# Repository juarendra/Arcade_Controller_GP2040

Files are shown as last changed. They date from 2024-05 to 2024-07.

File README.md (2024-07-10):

# Arcade_Controller_GP2040
Hardware and Firmware of Arcade Controller Based RP2040 as Microcontroller and GP2040 as Frimware

# Spesification
- Input Power VIA USB 5VDC
- GP2040 Controller Firmware
- Plugable Terminal Block and molex JST-XH for Port To External Item
- Pin Header 2x10 2.54 for Port To External Item
- LED RGB on BOARD
- Support RP2040 Raspberry Pi PICO or Weact RP2040
- I2C Port 
- LED Player Port with Resistor On board 330OHM
- 3v3 and GND port Molex for external perpose

# Privew Hardware 
<p align="center">
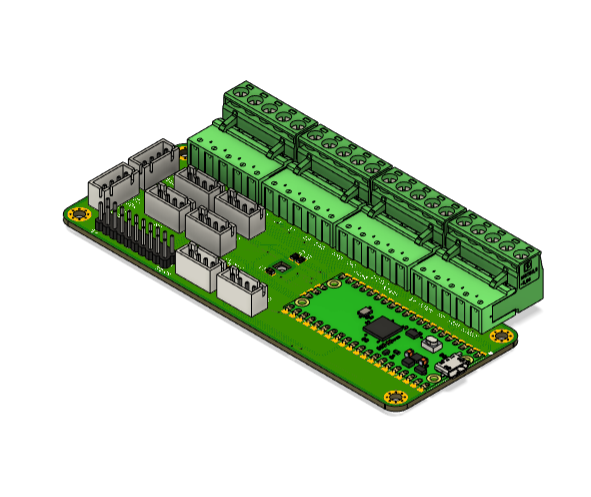
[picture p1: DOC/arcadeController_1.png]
  
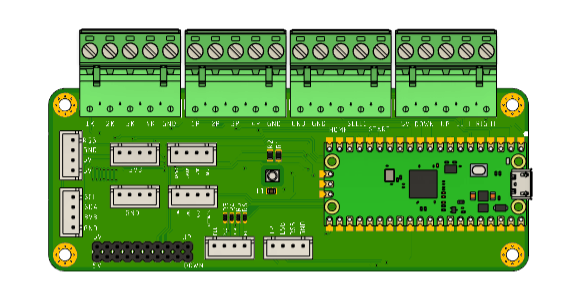
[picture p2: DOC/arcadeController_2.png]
  
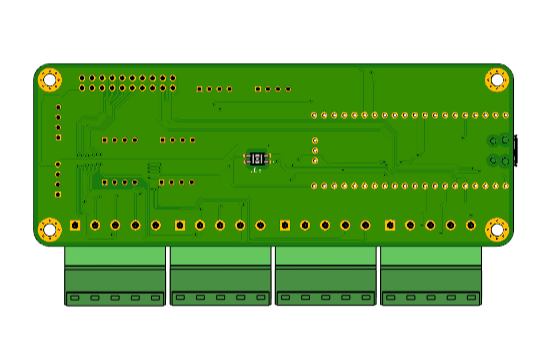
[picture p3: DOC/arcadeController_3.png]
  
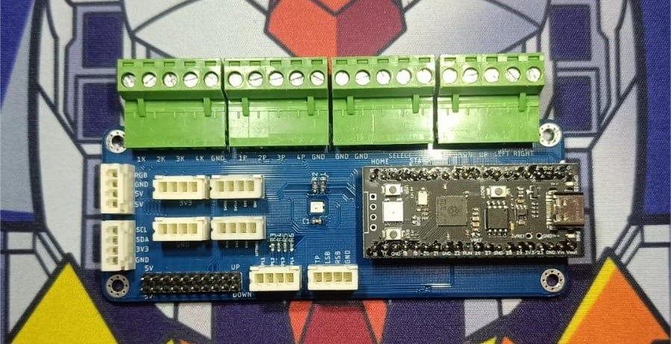
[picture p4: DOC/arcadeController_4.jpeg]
  
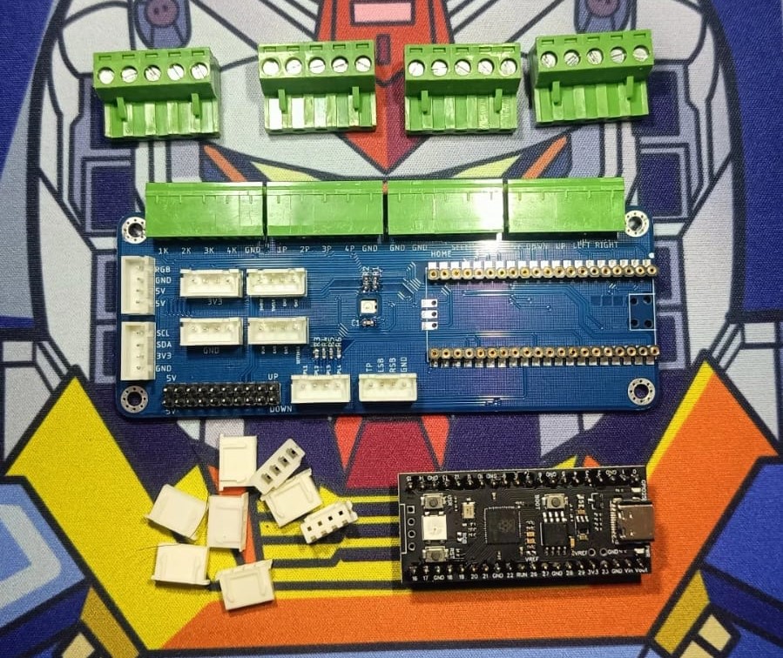
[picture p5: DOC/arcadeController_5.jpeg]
  
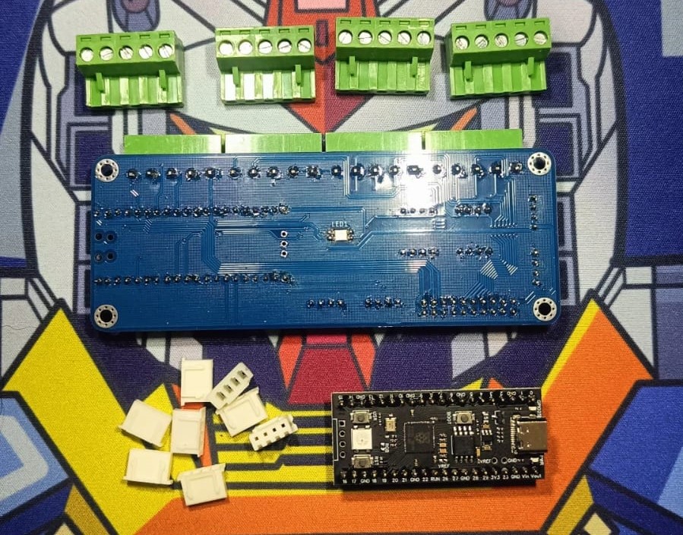
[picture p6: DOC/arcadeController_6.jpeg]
  
</p>

# Pinout
## Pinout RP2040
<p align="center">
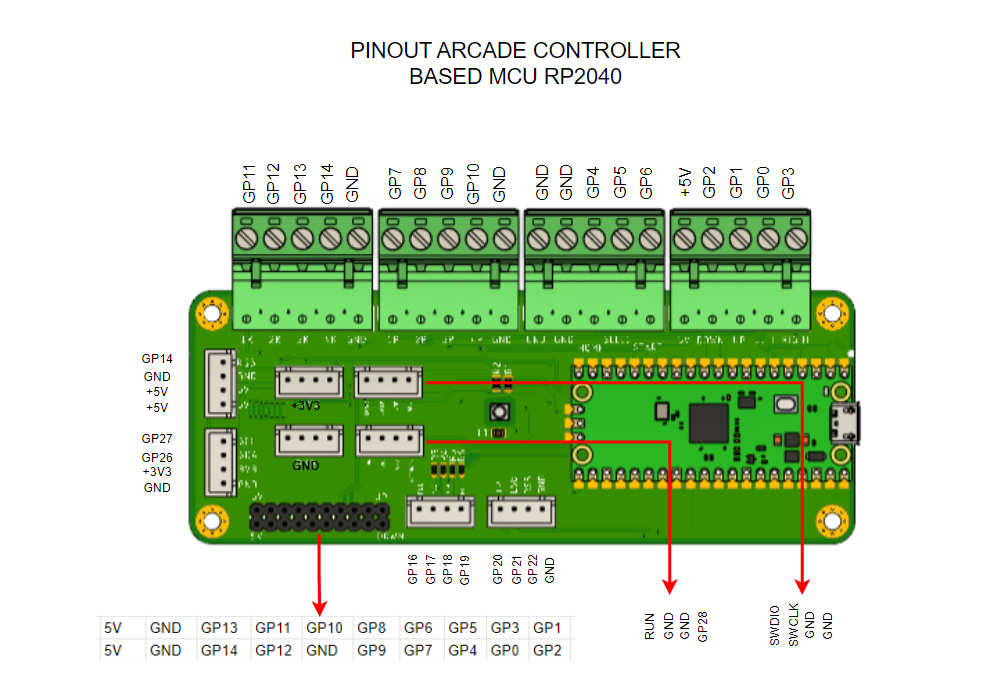
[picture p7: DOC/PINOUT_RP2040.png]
  
</p>

# Documentation 
- [Dimension](https://github.com/juarendra/Arcade_Controller_GP2040/blob/main/3D/Dimension_arcadeController.pdf)
- [BOM](https://github.com/juarendra/Arcade_Controller_GP2040/blob/main/DOC/bom.csv)
- [Pinout RP2040](https://github.com/juarendra/Arcade_Controller_GP2040/blob/main/DOC/Arcade_Controller_GP2040_Pinout.pdf)

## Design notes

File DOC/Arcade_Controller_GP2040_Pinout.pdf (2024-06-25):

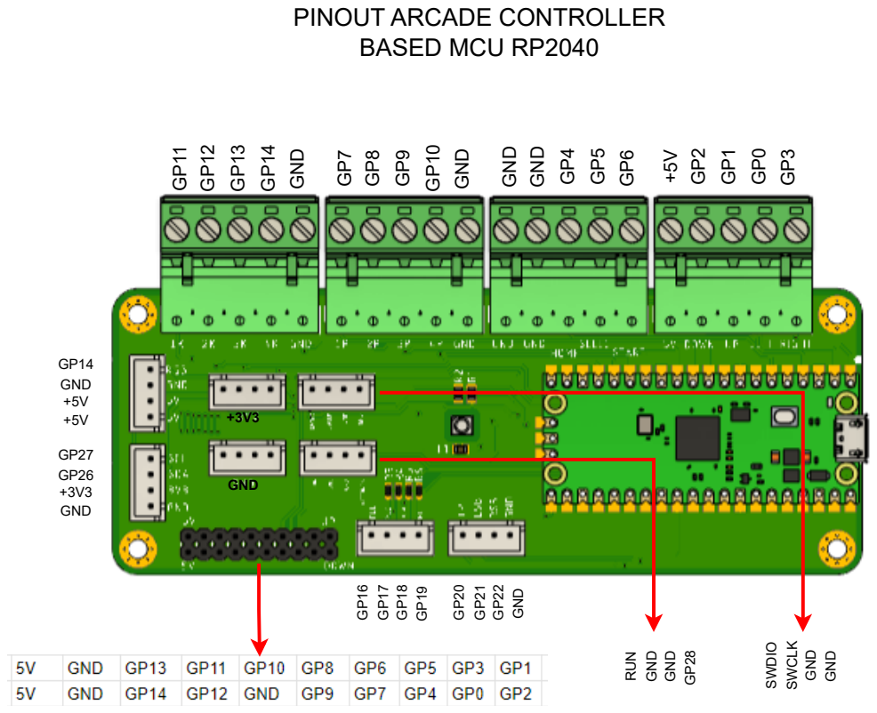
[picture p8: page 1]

PINOUT ARCADE CONTROLLER
BASED MCU RP2040

GP11

GP12

GP13

GP14
GND
GP7

GP8

GP9

GP10
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
GP14
GND
+5V
+5V

GP27
GP26
+3V3
GND

GND

+3V3

GP16

GP17

GP18
GP19

GP20
GP21

GP22
GND

SWDIO

SWCLK
RUN

GND
GND

GP28
GND
GND

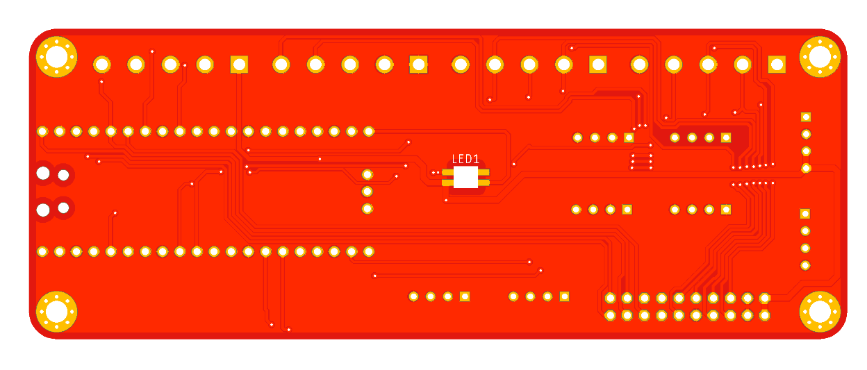
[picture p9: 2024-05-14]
DOC/rear_pcb.png

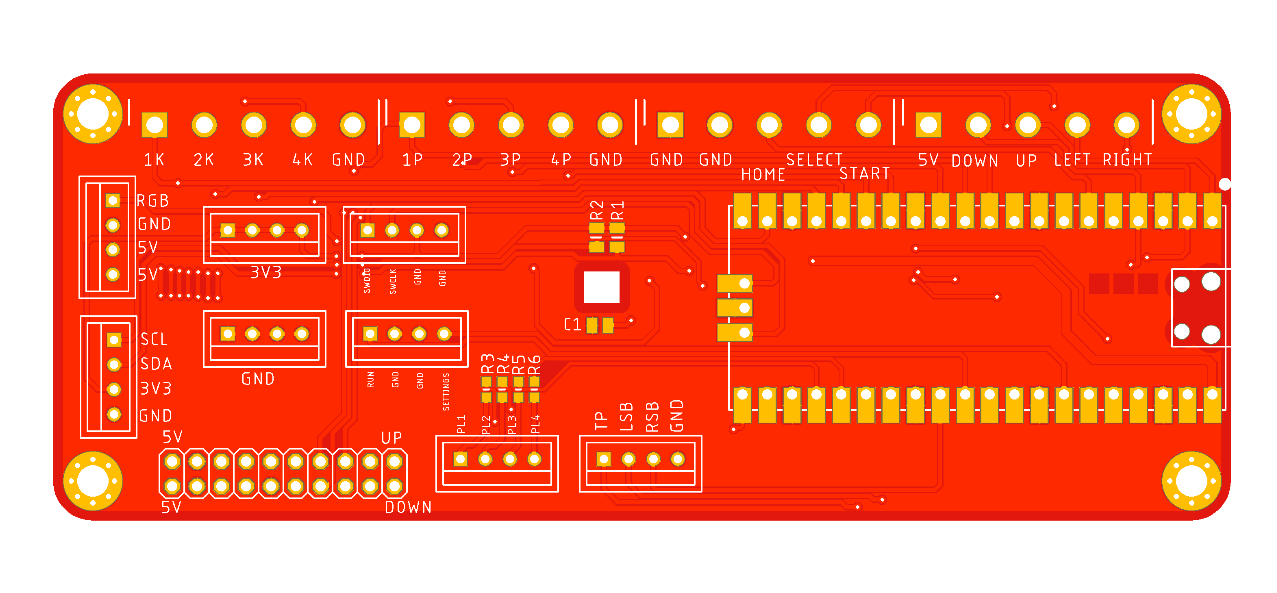
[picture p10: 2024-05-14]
DOC/front_pcb.png

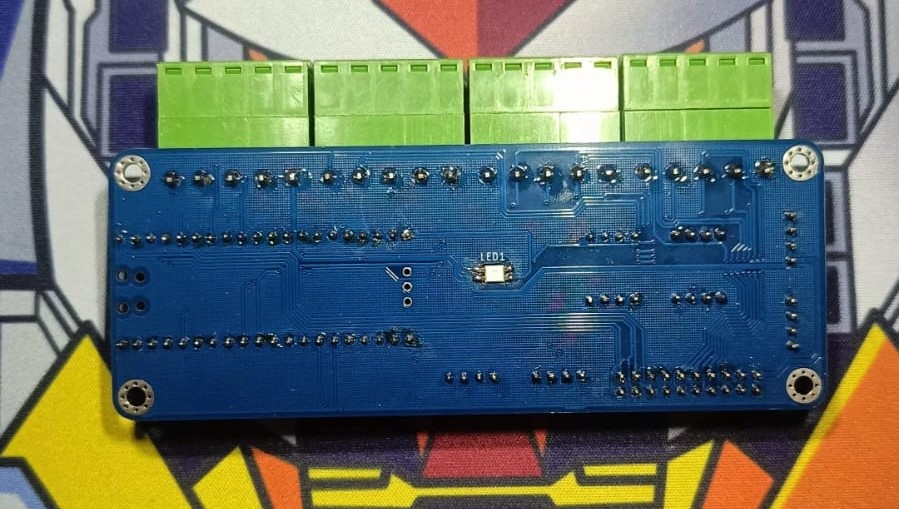
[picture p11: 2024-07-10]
DOC/arcadeController_7.jpeg

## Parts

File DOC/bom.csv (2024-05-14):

Qty | Value | Device | Package | Parts | Description | ARROW_PART_NUMBER | ARROW_PRICE-STOCK | DESCRIPTION | HEIGHT | MANUFACTURER_NAME | MANUFACTURER_PART_NUMBER | MOUSER_PART_NUMBER | MOUSER_PRICE-STOCK | POPULARITY
1 |  | PINHD-2X10 | 2X10 | JP1 | PIN HEADER |  |  |  |  |  |  |  |  | 7
8 | 04-JST-B4B-XH-A | 04-JST-B4B-XH-A | B4B-XH | X1, X2, X3, X4, X5, X6, X7, X8 | JST CONNECTOR
1 | 100nf | 08055C104K4T2A | CAPC2012X94N | C1 | AVX - 08055C104K4T2A - SMD Multilayer Ceramic Capacitor, 0.1 F, 50 V, 0805 [2012 Metric], +/- 10%, X7R |  |  | AVX - 08055C104K4T2A - SMD Multilayer Ceramic Capacitor, 0.1 F, 50 V, 0805 [2012 Metric], +/- 10%, X7R | 0.94mm | Kyocera AVX | 08055C104K4T2A | 581-08055C104K4 | https://www.mouser.co.uk/ProductDetail/KYOCERA-AVX/08055C104K4T2A?qs=xMTsDkQFXIwOG0s%252Bx1urSg%3D%3D
2 | 10k | CHP0805-FX-1002ELF | RESC2012X60N | R1, R2 | Thick Film Resistors - SMD ResHighPower 0805 10k 1% 1/2W TC100 |  |  | Thick Film Resistors - SMD ResHighPower 0805 10k 1% 1/2W TC100 | 0.6mm | Bourns | CHP0805-FX-1002ELF | 652-CHP0805FX1002ELF | https://www.mouser.co.uk/ProductDetail/Bourns/CHP0805-FX-1002ELF?qs=lc2O%252BfHJPVaDI6gsPdDtfw%3D%3D
4 | 1759046 | 1759046 | SHDRRA5W103P0X508_1X5_2540X120 | J2, J3, J4, J5 | PCB header, nominal cross section: 2.5 mm?, color: green, nominal current: 12 A, rated voltage (III/2): 320 V, contact surface: Tin, type of contact: Male connector, Number of potentials: 5, Number of rows: 1, Number of positions per row: 5, number of connections: 5, product range: MSTB 2,5/..-G, pitch: 5.08 mm, mounting: Wave soldering, pin layout: Linear pinning, solder pin [P]: 3.2 mm, Stecksystem: CLASSIC COMBICON, Locking: without, type of packaging: packed in cardboard |  |  | PCB header, nominal cross section: 2.5 mm?, color: green, nominal current: 12 A, rated voltage (III/2): 320 V, contact surface: Tin, type of contact: Male connector, Number of potentials: 5, Number of rows: 1, Number of positions per row: 5, number of connections: 5, product range: MSTB 2,5/..-G, pitch: 5.08 mm, mounting: Wave soldering, pin layout: Linear pinning, solder pin [P]: 3.2 mm, Stecksystem: CLASSIC COMBICON, Locking: without, type of packaging: packed in cardboard | 8.72mm | Phoenix Contact | 1759046 | 651-1759046 | https://www.mouser.co.uk/ProductDetail/Phoenix-Contact/1759046?qs=cyzODkzcbwC75vUJEckceg%3D%3D
4 | 330 | CMP0603AFX-3300ELF | RESC1608X55N | R3, R4, R5, R6 | Thick Film Resistors - SMD 330 OHM 1% 1/4W TC100 |  |  | Thick Film Resistors - SMD 330 OHM 1% 1/4W TC100 | 0.55mm | Bourns | CMP0603AFX-3300ELF | 652-CMP0603AFX-3300L | https://www.mouser.co.uk/ProductDetail/Bourns/CMP0603AFX-3300ELF?qs=TiOZkKH1s2QD9kDdDwF%252BdA%3D%3D
4 | 3MM_HOLE | 3MM_HOLE | 3MM_HOLE | H1, H2, H3, H4 | Cool looking 3mm hole with ground connection
1 | RASPBERRY_PICOSMD-TH | RASPBERRY_PICOSMD-TH | PICO-PKG | U1 | Raspberry Pi Pico
1 | SK6812MINI-E | SK6812MINI-E | SK6812MINIE | LED1 | 3.2x2.8x1.78 mm 0.2W Intelligent external control surface mount SMD LED (MSL:5a) |  |  | 3.2x2.8x1.78 mm 0.2W Intelligent external control surface mount SMD LED (MSL:5a) | 1.88mm | Yellow Stone Corp. | SK6812MINI-E

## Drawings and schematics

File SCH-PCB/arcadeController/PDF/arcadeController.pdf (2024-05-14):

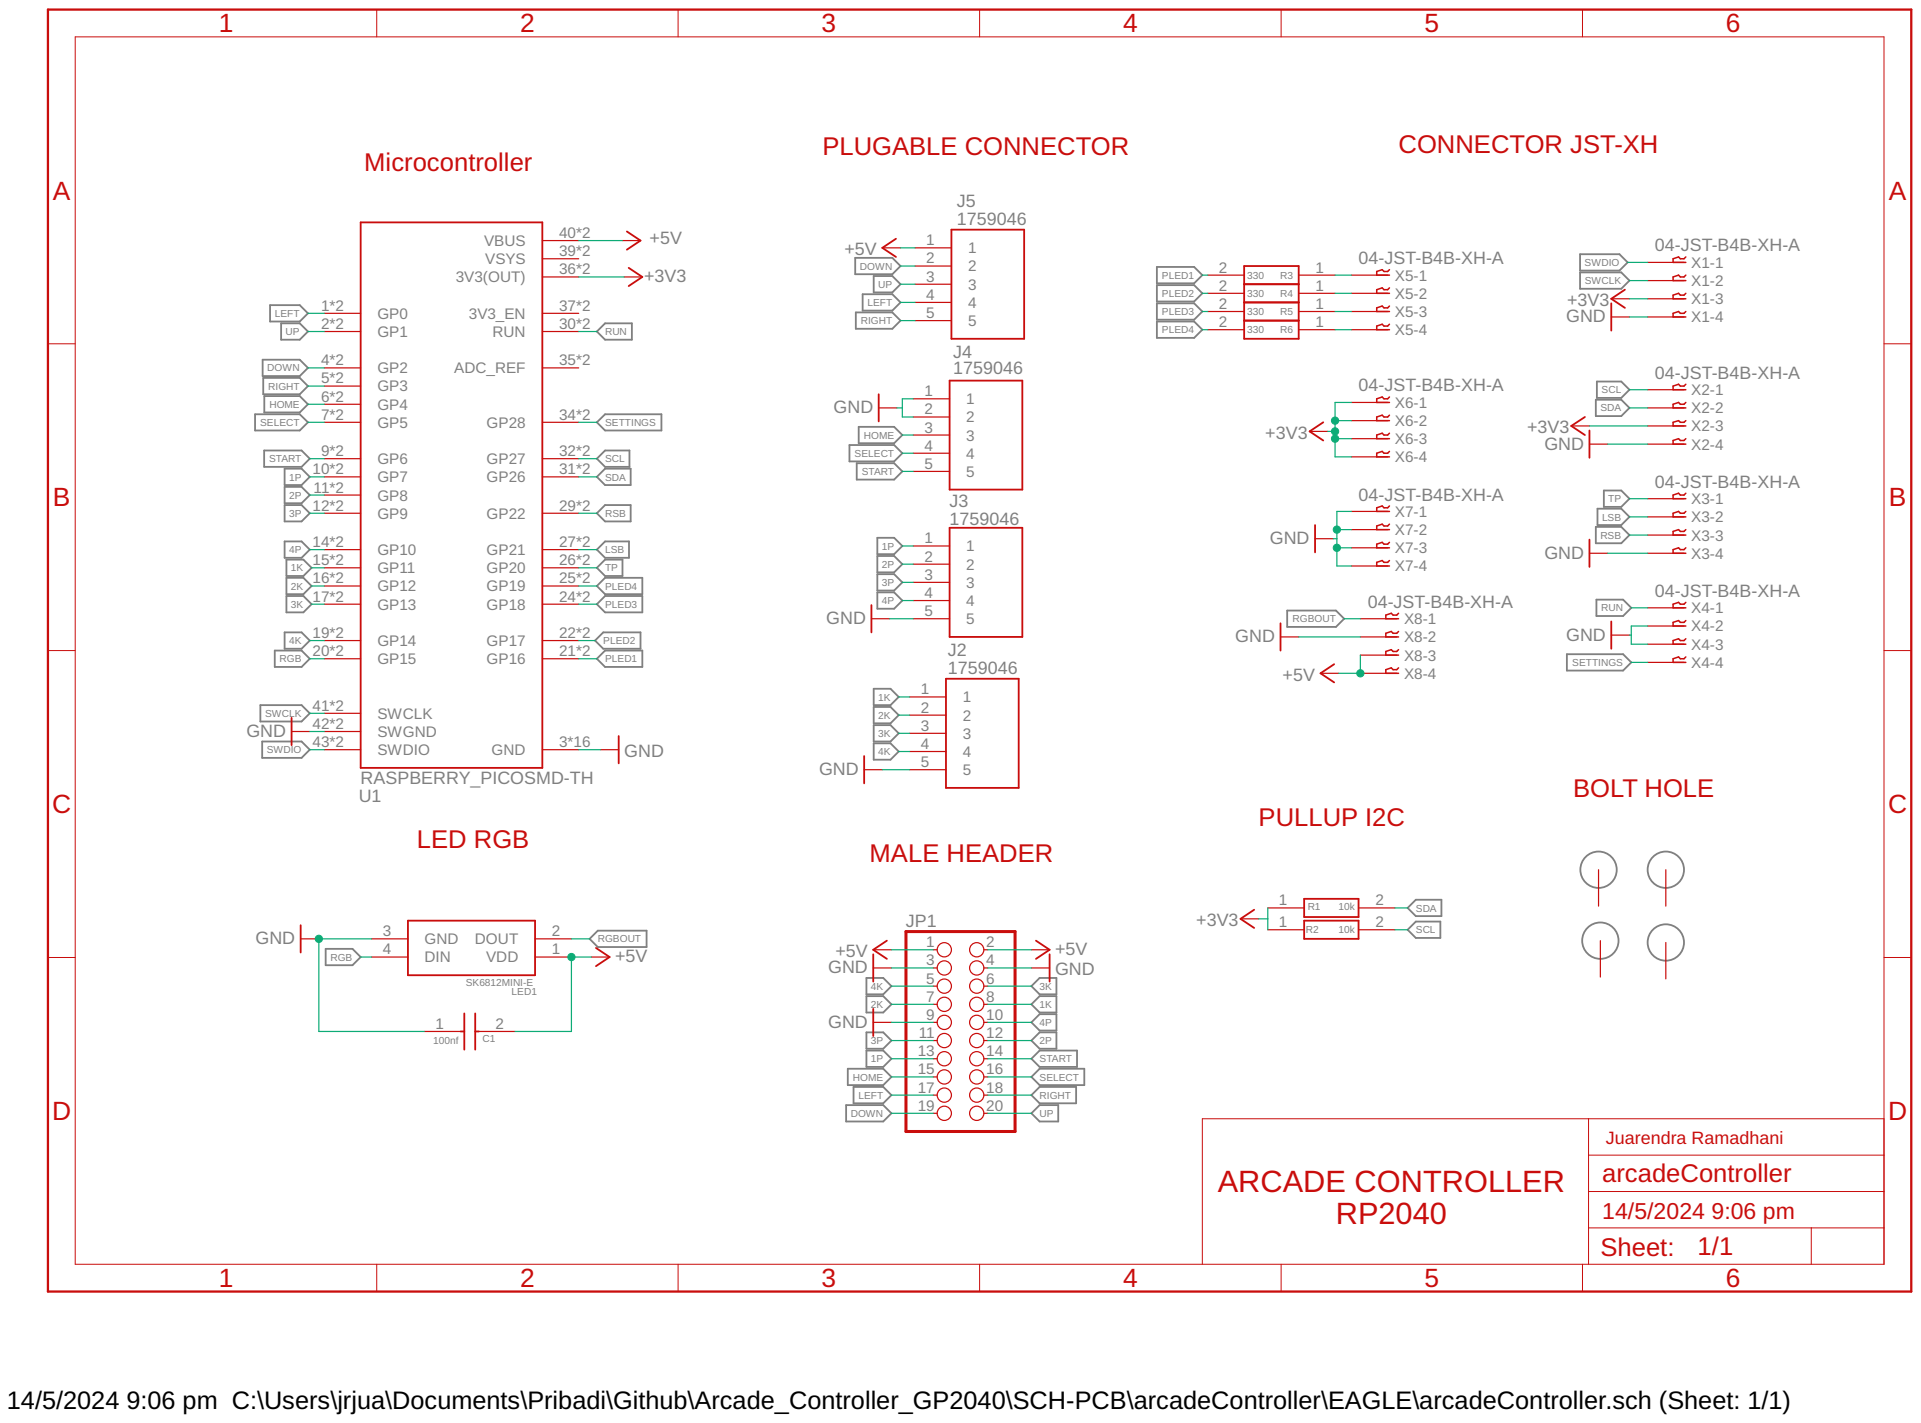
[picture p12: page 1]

14/5/2024 9:06 pm C:\Users\jrjua\Documents\Pribadi\Github\Arcade_Controller_GP2040\SCH-PCB\arcadeController\EAGLE\arcadeController.sch (Sheet: 1/1)

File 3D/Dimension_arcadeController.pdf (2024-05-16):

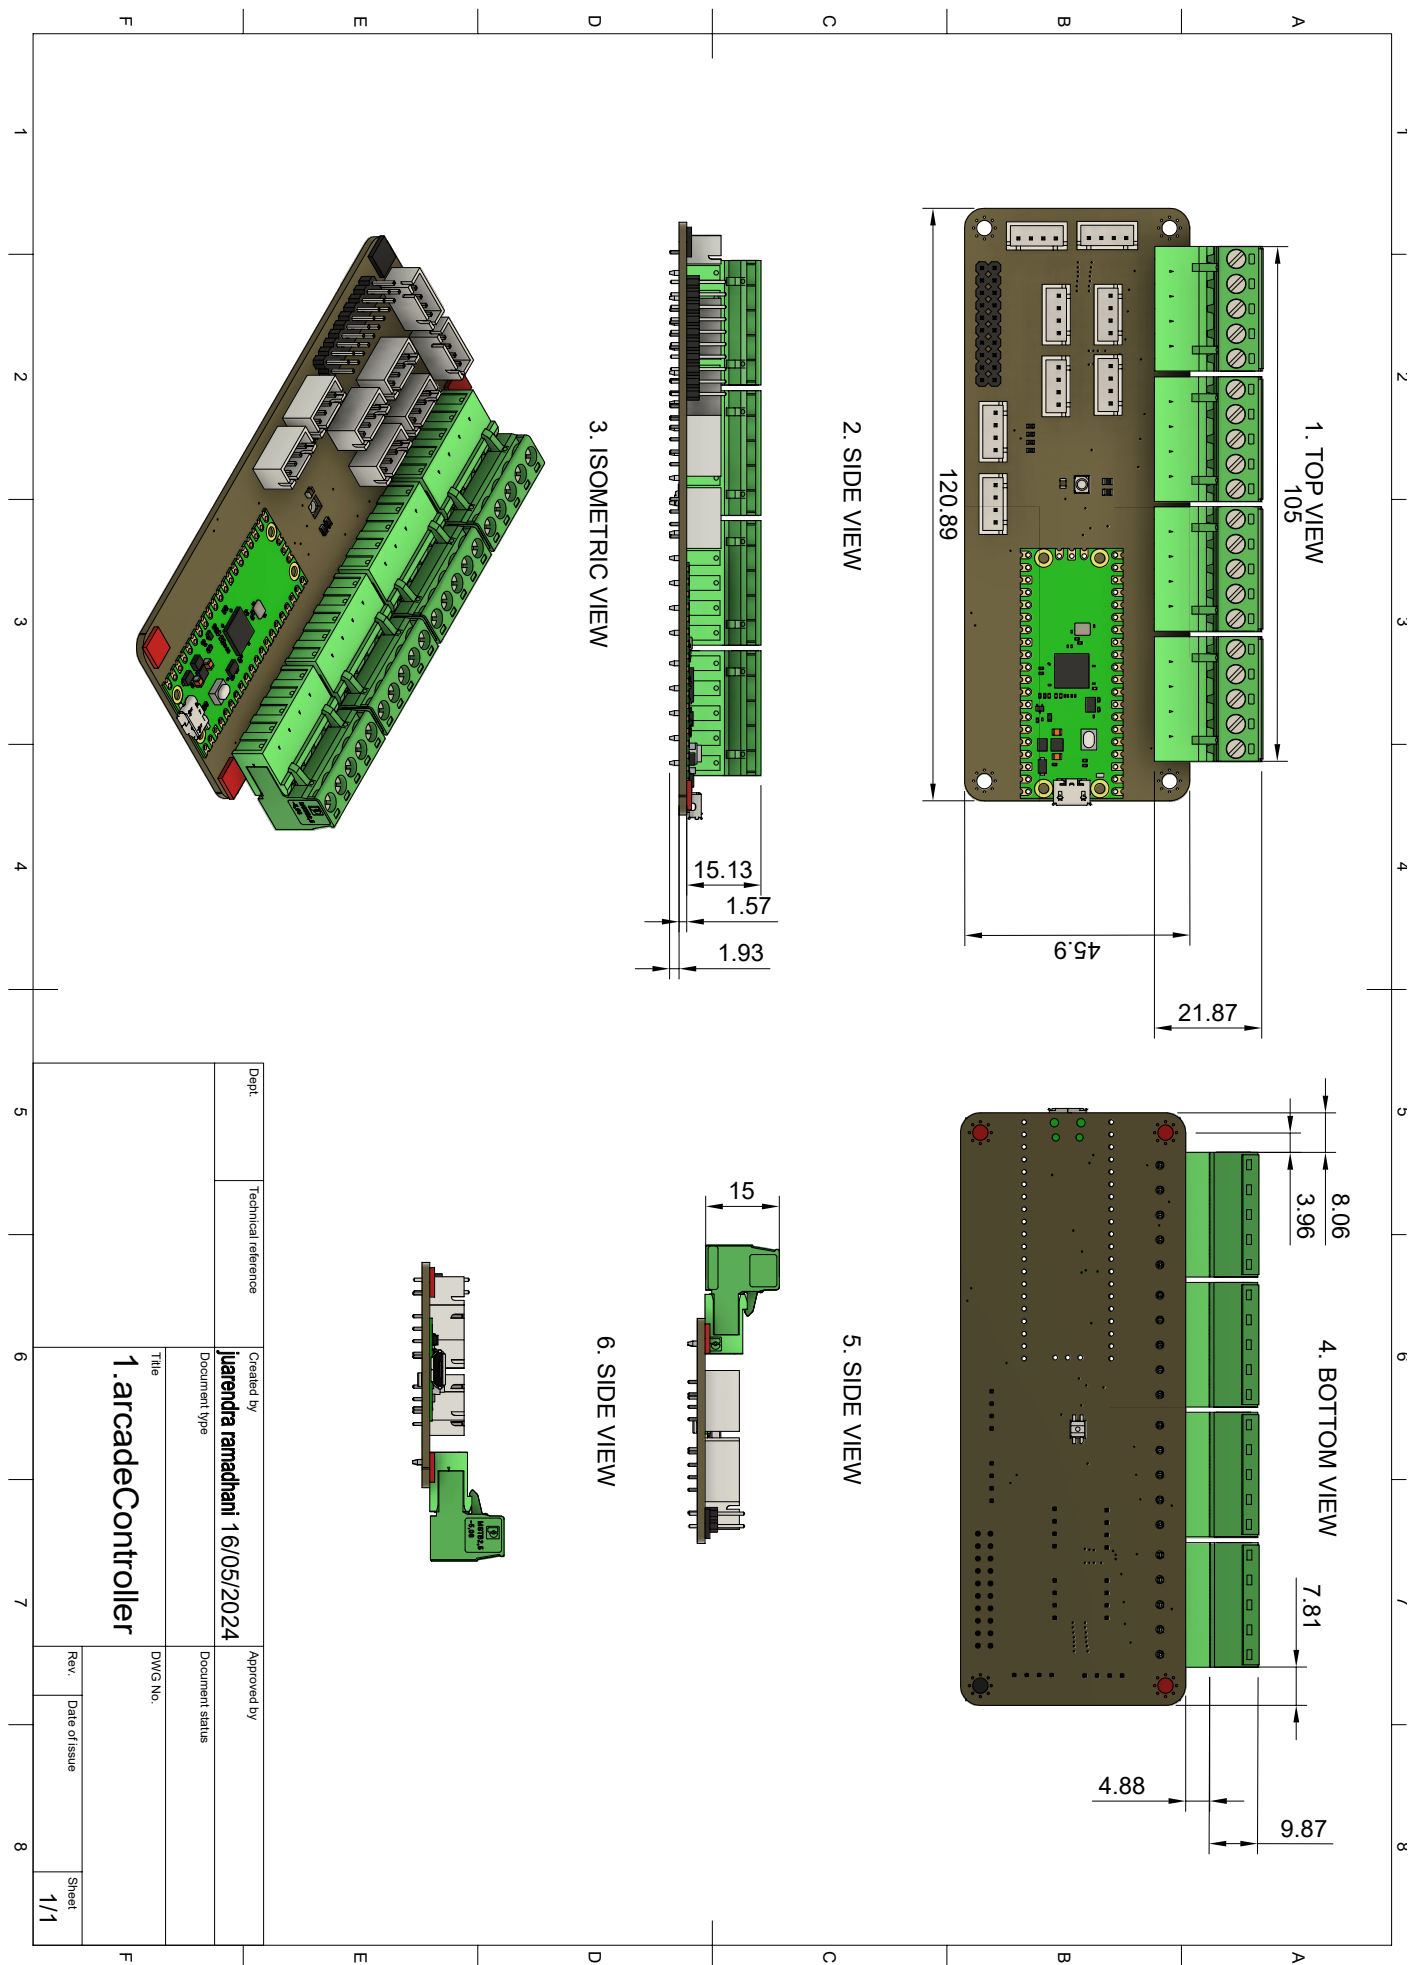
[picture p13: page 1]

1 A 2 3 4 5 6 7 8 1 2 3 4 5 6 7 8 FEDCB FEDCBA Dept. Technical reference Created by Approved by Title DWG No. Document type Document status Rev. Date of issue Sheet 16/05/2024 1/1 1.arcadeController 3. ISOMETRIC VIEW 2. SIDE VIEW 1. TOP VIEW 6. SIDE VIEW 5. SIDE VIEW 4. BOTTOM VIEW

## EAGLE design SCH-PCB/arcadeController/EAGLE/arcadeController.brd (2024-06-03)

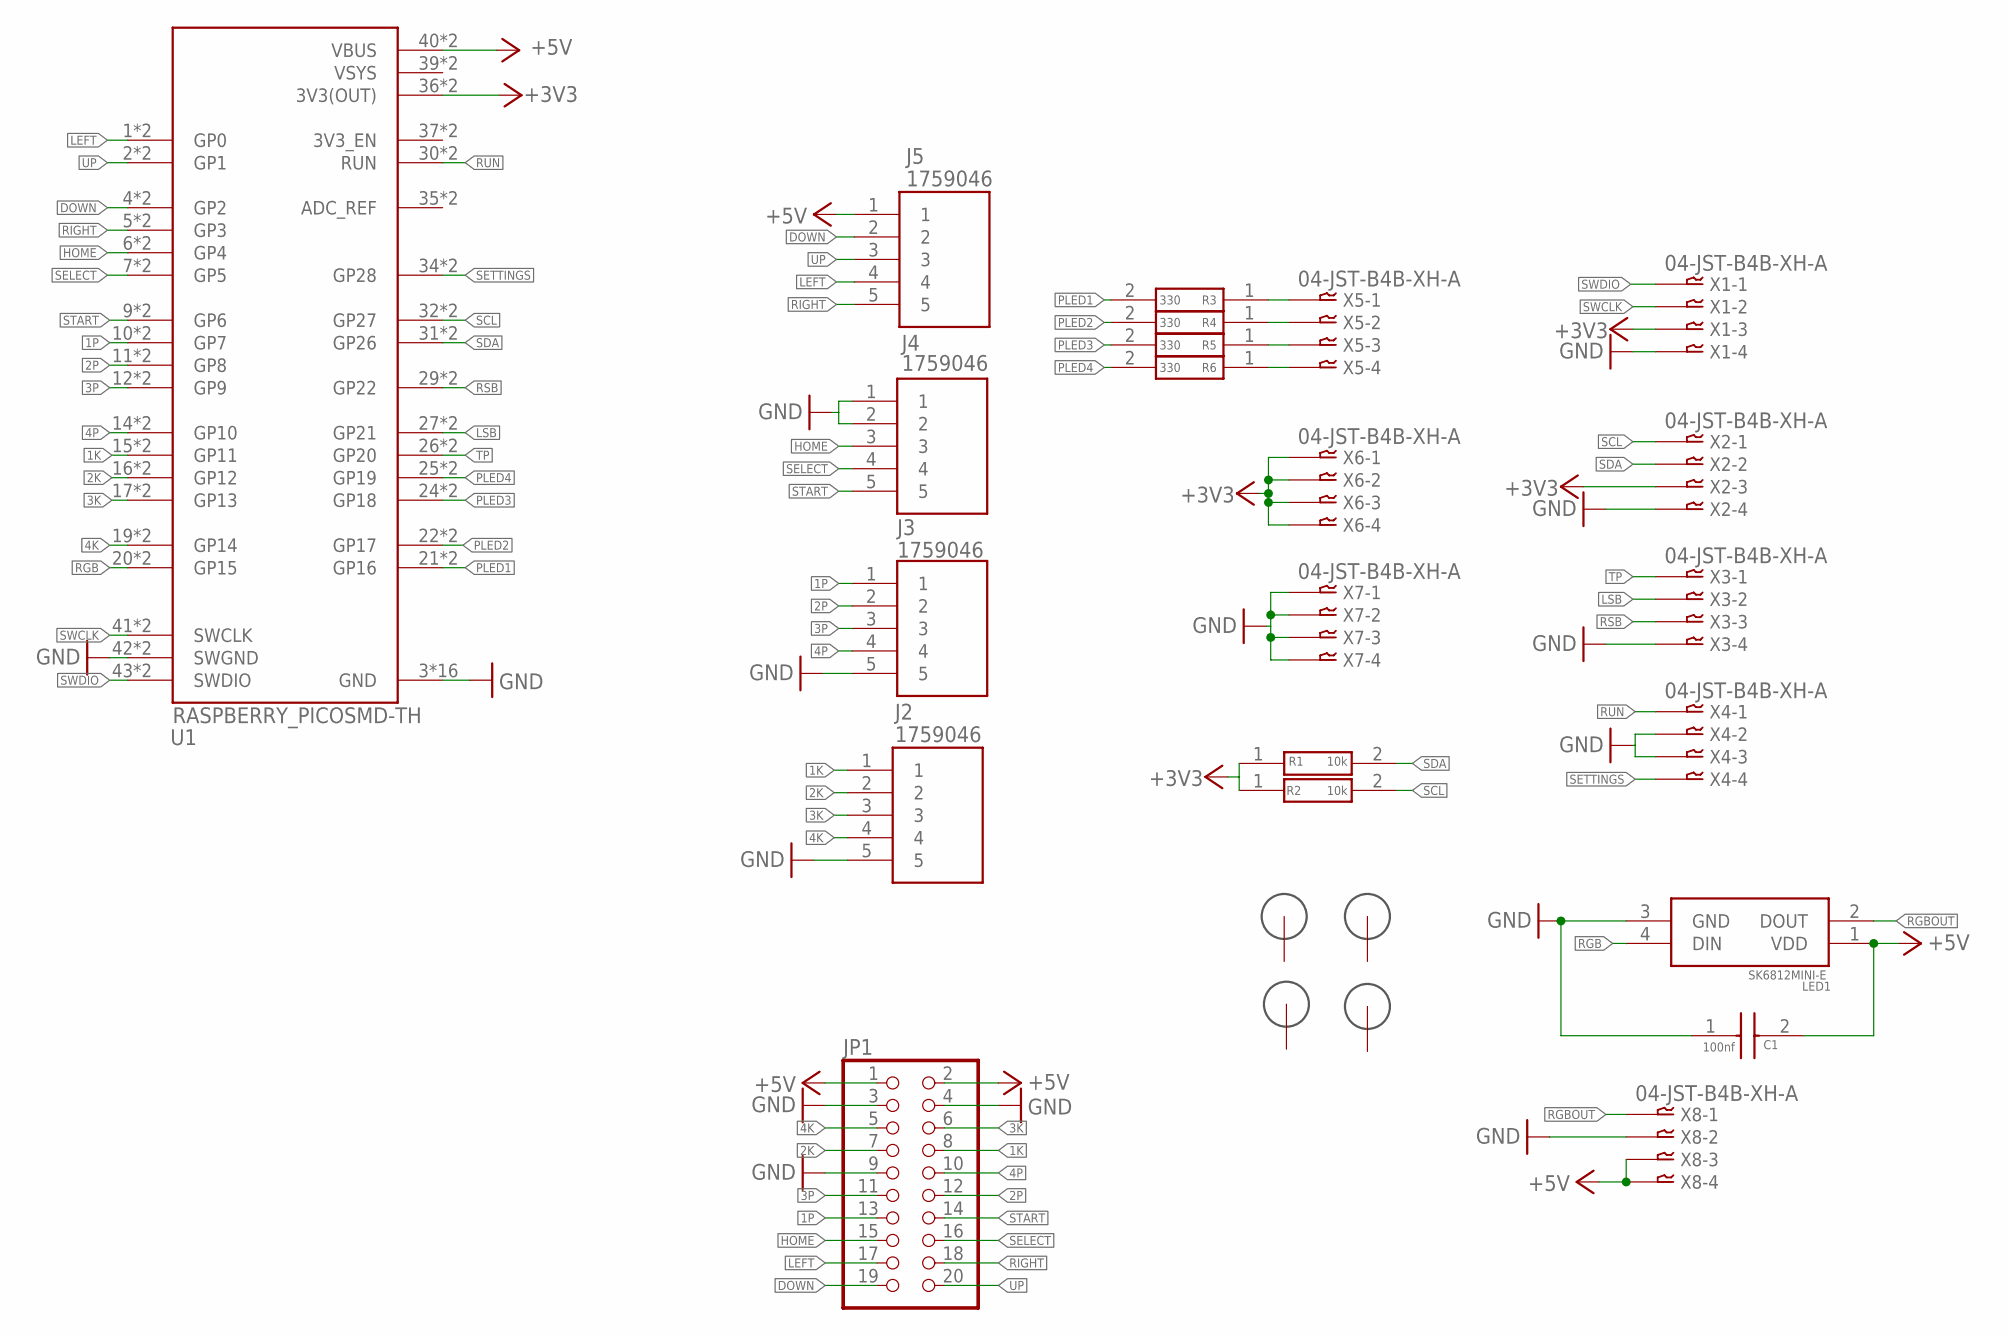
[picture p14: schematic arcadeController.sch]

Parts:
C1: 100nf; CAPC2012X94N
H1, H2, H3, H4: 3MM_HOLE
J2, J3, J4, J5: 1759046; SHDRRA5W103P0X508_1X5_2540X120
JP1: PINHD-2X10; 2X10
LED1: SK6812MINI-E; SK6812MINIE
R1, R2: 10k; RESC2012X60N
R3, R4, R5, R6: 330; RESC1608X55N
U1: RASPBERRY_PICOSMD-TH; PICO-PKG
X1, X2, X3, X4, X5, X6, X7, X8: 04-JST-B4B-XH-A; B4B-XH

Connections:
1K: J2.1, JP1.8, U1.15 (GP11), U1.P$15 (GP11)
1P: J3.1, JP1.13, U1.10 (GP7), U1.P$10 (GP7)
2K: J2.2, JP1.7, U1.16 (GP12), U1.P$16 (GP12)
2P: J3.2, JP1.12, U1.11 (GP8), U1.P$11 (GP8)
3K: J2.3, JP1.6, U1.17 (GP13), U1.P$17 (GP13)
3P: J3.3, JP1.11, U1.12 (GP9), U1.P$12 (GP9)
4K: J2.4, JP1.5, U1.19 (GP14), U1.P$19 (GP14)
4P: J3.4, JP1.10, U1.14 (GP10), U1.P$14 (GP10)
+3V3: R1.1, R2.1, U1.36 (3V3(OUT)), U1.P$36 (3V3(OUT)), X1.P$3, X2.P$3, X6.P$1, X6.P$2, X6.P$3, X6.P$4
+5V: C1.2, J5.1, JP1.1, JP1.2, LED1.1 (VDD), U1.40 (VBUS), U1.P$40 (VBUS), X8.P$3, X8.P$4
DOWN: J5.2, JP1.19, U1.4 (GP2), U1.P$4 (GP2)
GND: C1.1, J2.5, J3.5, J4.1, J4.2, JP1.3, JP1.4, JP1.9, LED1.3 (GND), U1.3 (GND), U1.8 (GND), U1.13 (GND), U1.18 (GND), U1.23 (GND), U1.28 (GND), U1.33 (GND), U1.38 (GND), U1.42 (SWGND), U1.P$3 (GND), U1.P$8 (GND), U1.P$13 (GND), U1.P$18 (GND), U1.P$23 (GND), U1.P$28 (GND), U1.P$33 (GND), U1.P$38 (GND), U1.P$42 (SWGND), X1.P$4, X2.P$4, X3.P$4, X4.P$2, X4.P$3, X7.P$1, X7.P$2, X7.P$3, X7.P$4, X8.P$2
HOME: J4.3, JP1.15, U1.6 (GP4), U1.P$6 (GP4)
LEFT: J5.4, JP1.17, U1.1 (GP0), U1.P$1 (GP0)
LSB: U1.27 (GP21), U1.P$27 (GP21), X3.P$2
unnamed: R3.1, X5.P$1
unnamed: R4.1, X5.P$2
unnamed: R5.1, X5.P$3
unnamed: R6.1, X5.P$4
PLED1: R3.2, U1.21 (GP16), U1.P$21 (GP16)
PLED2: R4.2, U1.22 (GP17), U1.P$22 (GP17)
PLED3: R5.2, U1.24 (GP18), U1.P$24 (GP18)
PLED4: R6.2, U1.25 (GP19), U1.P$25 (GP19)
RGB: LED1.4 (DIN), U1.20 (GP15), U1.P$20 (GP15)
RGBOUT: LED1.2 (DOUT), X8.P$1
RIGHT: J5.5, JP1.18, U1.5 (GP3), U1.P$5 (GP3)
RSB: U1.29 (GP22), U1.P$29 (GP22), X3.P$3
RUN: U1.30 (RUN), U1.P$30 (RUN), X4.P$1
SCL: R2.2, U1.32 (GP27), U1.P$32 (GP27), X2.P$1
SDA: R1.2, U1.31 (GP26), U1.P$31 (GP26), X2.P$2
SELECT: J4.4, JP1.16, U1.7 (GP5), U1.P$7 (GP5)
SETTINGS: U1.34 (GP28), U1.P$34 (GP28), X4.P$4
START: J4.5, JP1.14, U1.9 (GP6), U1.P$9 (GP6)
SWCLK: U1.41 (SWCLK), U1.P$41 (SWCLK), X1.P$2
SWDIO: U1.43 (SWDIO), U1.P$43 (SWDIO), X1.P$1
TP: U1.26 (GP20), U1.P$26 (GP20), X3.P$1
UP: J5.3, JP1.20, U1.2 (GP1), U1.P$2 (GP1)
VSYS: U1.39 (VSYS), U1.P$39 (VSYS)

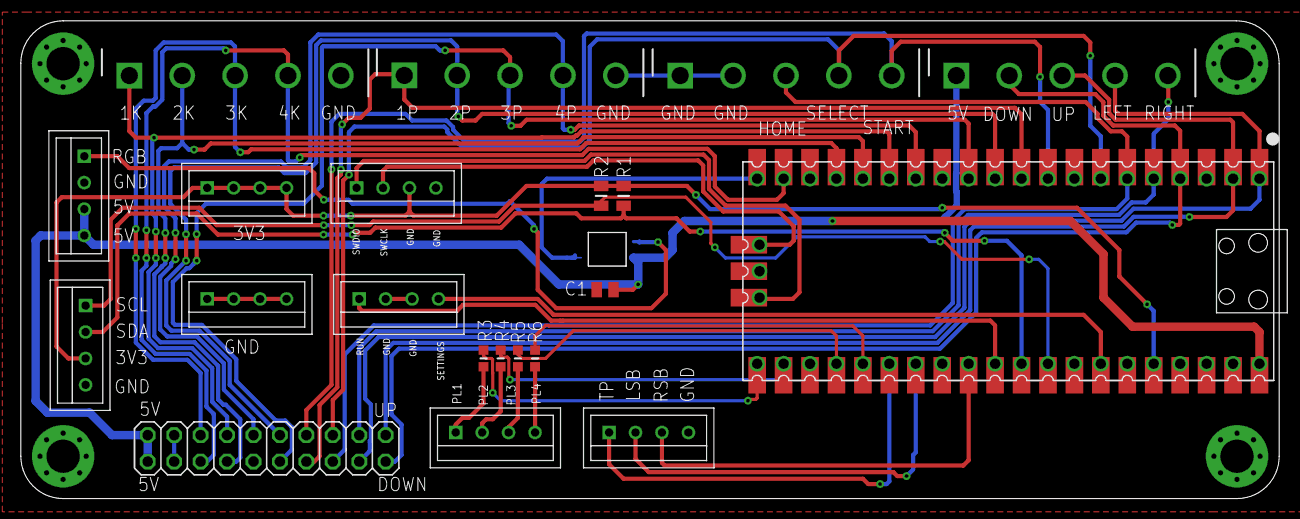
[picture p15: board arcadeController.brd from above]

Board: 2 copper layers, 120.9 x 45.9 mm, 26 parts (1 on the bottom side), 38 nets.

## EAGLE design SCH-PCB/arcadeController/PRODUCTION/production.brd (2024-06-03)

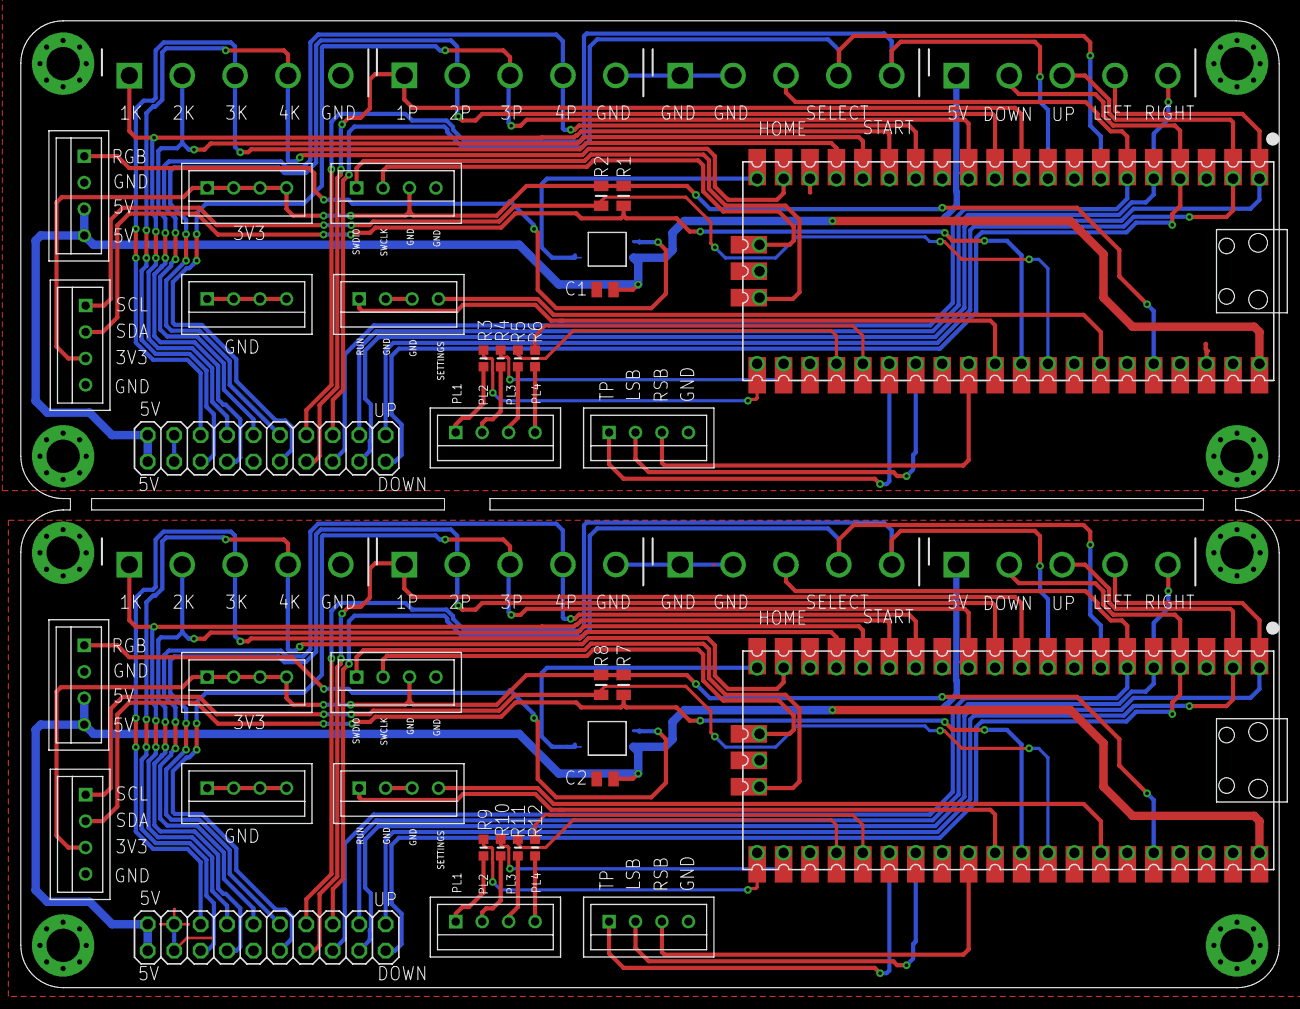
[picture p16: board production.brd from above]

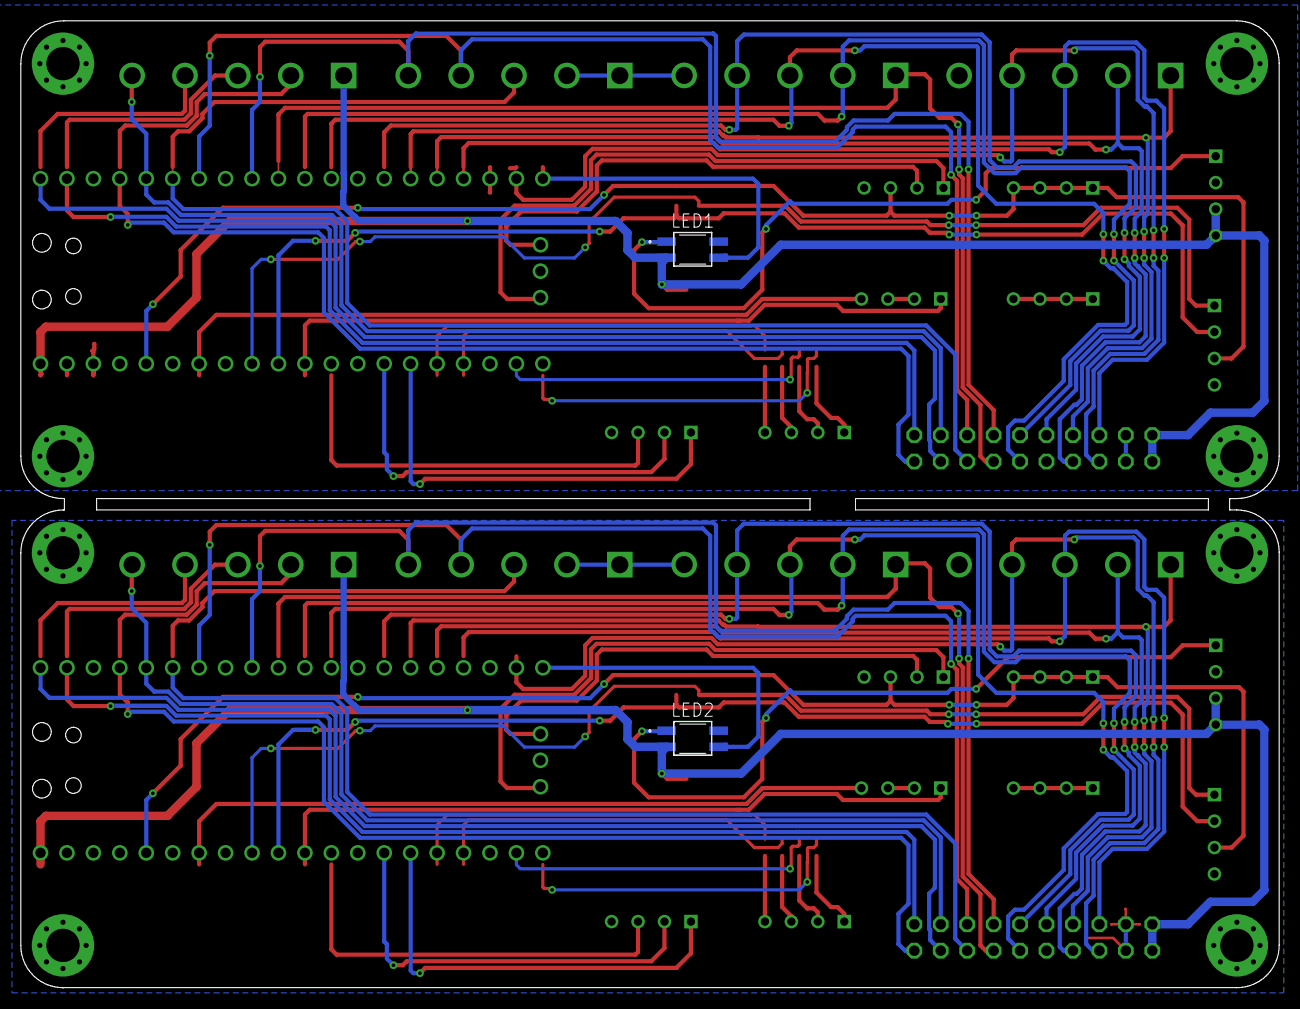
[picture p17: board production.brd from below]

Board: 2 copper layers, 120.9 x 92.9 mm, 52 parts (2 on the bottom side), 76 nets.

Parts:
C1, C2: 100nf; CAPC2012X94N
H1, H2, H3, H4, H5, H6, H7, H8: 3MM_HOLE
J1, J2, J3, J4, J5, J6, J7, J8: 1759046; SHDRRA5W103P0X508_1X5_2540X120
JP1, JP2: 2X10
LED1, LED2: SK6812MINI-E; SK6812MINIE
R1, R2, R7, R8: 10k; RESC2012X60N
R3, R4, R5, R6, R9, R10, R11, R12: 330; RESC1608X55N
U1, U2: RASPBERRY_PICOSMD-TH; PICO-PKG
X1, X2, X3, X4, X5, X6, X7, X8, X9, X10, X11, X12, X13, X14, X15, X16: 04-JST-B4B-XH-A; B4B-XH

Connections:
1K: J2.1, JP1.8, U1.15, U1.P$15
1K1: J1.1, JP2.8, U2.15, U2.P$15
1P: J3.1, JP1.13, U1.10, U1.P$10
1P1: J6.1, JP2.13, U2.10, U2.P$10
2K: J2.2, JP1.7, U1.16, U1.P$16
2K1: J1.2, JP2.7, U2.16, U2.P$16
2P: J3.2, JP1.12, U1.11, U1.P$11
2P1: J6.2, JP2.12, U2.11, U2.P$11
3K: J2.3, JP1.6, U1.17, U1.P$17
3K1: J1.3, JP2.6, U2.17, U2.P$17
3P: J3.3, JP1.11, U1.12, U1.P$12
3P1: J6.3, JP2.11, U2.12, U2.P$12
4K: J2.4, JP1.5, U1.19, U1.P$19
4K1: J1.4, JP2.5, U2.19, U2.P$19
4P: J3.4, JP1.10, U1.14, U1.P$14
4P1: J6.4, JP2.10, U2.14, U2.P$14
+3V1: R7.1, R8.1, U2.36, U2.P$36, X9.P$3, X10.P$3, X14.P$1, X14.P$2, X14.P$3, X14.P$4
+3V3: R1.1, R2.1, U1.36, U1.P$36, X1.P$3, X2.P$3, X6.P$1, X6.P$2, X6.P$3, X6.P$4
+5V: C1.2, J5.1, JP1.1, JP1.2, LED1.1, U1.40, U1.P$40, X8.P$3, X8.P$4
+5V1: C2.2, J8.1, JP2.1, JP2.2, LED2.1, U2.40, U2.P$40, X16.P$3, X16.P$4
DOWN: J5.2, JP1.19, U1.4, U1.P$4
DOWN1: J8.2, JP2.19, U2.4, U2.P$4
GND: C1.1, J2.5, J3.5, J4.1, J4.2, JP1.3, JP1.4, JP1.9, LED1.3, U1.3, U1.8, U1.13, U1.18, U1.23, U1.28, U1.33, U1.38, U1.42, U1.P$3, U1.P$8, U1.P$13, U1.P$18, U1.P$23, U1.P$28, U1.P$33, U1.P$38, U1.P$42, X1.P$4, X2.P$4, X3.P$4, X4.P$2, X4.P$3, X7.P$1, X7.P$2, X7.P$3, X7.P$4, X8.P$2
GND1: C2.1, J1.5, J6.5, J7.1, J7.2, JP2.3, JP2.4, JP2.9, LED2.3, U2.3, U2.8, U2.13, U2.18, U2.23, U2.28, U2.33, U2.38, U2.42, U2.P$3, U2.P$8, U2.P$13, U2.P$18, U2.P$23, U2.P$28, U2.P$33, U2.P$38, U2.P$42, X9.P$4, X10.P$4, X11.P$4, X12.P$2, X12.P$3, X15.P$1, X15.P$2, X15.P$3, X15.P$4, X16.P$2
HOME: J4.3, JP1.15, U1.6, U1.P$6
HOME1: J7.3, JP2.15, U2.6, U2.P$6
LEFT: J5.4, JP1.17, U1.1, U1.P$1
LEFT1: J8.4, JP2.17, U2.1, U2.P$1
LSB: U1.27, U1.P$27, X3.P$2
LSB1: U2.27, U2.P$27, X11.P$2
unnamed: R9.1, X13.P$1
unnamed: R10.1, X13.P$2
unnamed: R11.1, X13.P$3
unnamed: R12.1, X13.P$4
unnamed: R3.1, X5.P$1
unnamed: R4.1, X5.P$2
unnamed: R5.1, X5.P$3
unnamed: R6.1, X5.P$4
PLED1: R3.2, U1.21, U1.P$21
PLED2: R4.2, U1.22, U1.P$22
PLED3: R5.2, U1.24, U1.P$24
PLED4: R6.2, U1.25, U1.P$25
PLED5: R9.2, U2.21, U2.P$21
PLED6: R10.2, U2.22, U2.P$22
PLED7: R11.2, U2.24, U2.P$24
PLED8: R12.2, U2.25, U2.P$25
RGB: LED1.4, U1.20, U1.P$20
RGB1: LED2.4, U2.20, U2.P$20
RGBOUT: LED1.2, X8.P$1
RGBOUT1: LED2.2, X16.P$1
RIGHT: J5.5, JP1.18, U1.5, U1.P$5
RIGHT1: J8.5, JP2.18, U2.5, U2.P$5
RSB: U1.29, U1.P$29, X3.P$3
RSB1: U2.29, U2.P$29, X11.P$3
RUN: U1.30, U1.P$30, X4.P$1
RUN1: U2.30, U2.P$30, X12.P$1
SCL: R2.2, U1.32, U1.P$32, X2.P$1
SCL1: R8.2, U2.32, U2.P$32, X10.P$1
SDA: R1.2, U1.31, U1.P$31, X2.P$2
SDA1: R7.2, U2.31, U2.P$31, X10.P$2
SELECT: J4.4, JP1.16, U1.7, U1.P$7
SELECT1: J7.4, JP2.16, U2.7, U2.P$7
SETTINGS: U1.34, U1.P$34, X4.P$4
SETTINGS1: U2.34, U2.P$34, X12.P$4
START: J4.5, JP1.14, U1.9, U1.P$9
START1: J7.5, JP2.14, U2.9, U2.P$9
SWCLK: U1.41, U1.P$41, X1.P$2
SWCLK1: U2.41, U2.P$41, X9.P$2
SWDIO: U1.43, U1.P$43, X1.P$1
SWDIO1: U2.43, U2.P$43, X9.P$1
TP: U1.26, U1.P$26, X3.P$1
TP1: U2.26, U2.P$26, X11.P$1
UP: J5.3, JP1.20, U1.2, U1.P$2
UP1: J8.3, JP2.20, U2.2, U2.P$2
VSYS: U1.39, U1.P$39
VSYS1: U2.39, U2.P$39

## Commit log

2024-05-16 FEAT: add BOM
    [bom.csv]
2024-06-03 FIX: PCB design there are line with <0.1mm
    [arcadeController.brd, arcadeController.sch, production.brd]
